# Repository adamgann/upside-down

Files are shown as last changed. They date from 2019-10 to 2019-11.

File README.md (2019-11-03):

# upside-down
Halloween 2019: The wall of lights from Stranger Things

---
In this costume an Arduino Uno, several shift registers (74HC595), and a handful of LEDs were used to create the wall from the first season of Stranger Things. The result can be seen [in this video](https://www.youtube.com/watch?v=mKRO_VgZO74) and the build process is discussed in [this blog post](http://adamgannon.com/2019/11/03/an-arduino-powered-stranger-things-costume/).

All design files are available to use (see terms in LICENSE). A warning this was hacked together fairly quickly, so don't expect a graceful board layout or bug-free software. Please cite this repository or my blog.

---
## Files

### arduino/
Contains Arudino sketches. Partly based on examples from [Janis Rove](https://github.com/janisrove/Arduino-74HC595-shift-registers) and the folks at [Adafruit](https://learn.adafruit.com/adafruit-arduino-lesson-4-eight-leds/brightness-control).

The sketch `check_leds.ino` cycles through each letter of the alphabet to verify wiring is correct.

The sketch `main.ino` runs through the light sequence.

### eagle/
Contains schematic and design files for the PCB. The project name is `shift_register_board`. Huge thanks to the [Sparkfun Eagle library](https://github.com/sparkfun/SparkFun-Eagle-Libraries) for footprints.

### graphics/
Files for the silkscreen logo added to the board. I followed the Eagle BMP import process discussed [in this tutorial](https://learn.sparkfun.com/tutorials/importing-custom-images-into-eagle/method-3-import-bmp).

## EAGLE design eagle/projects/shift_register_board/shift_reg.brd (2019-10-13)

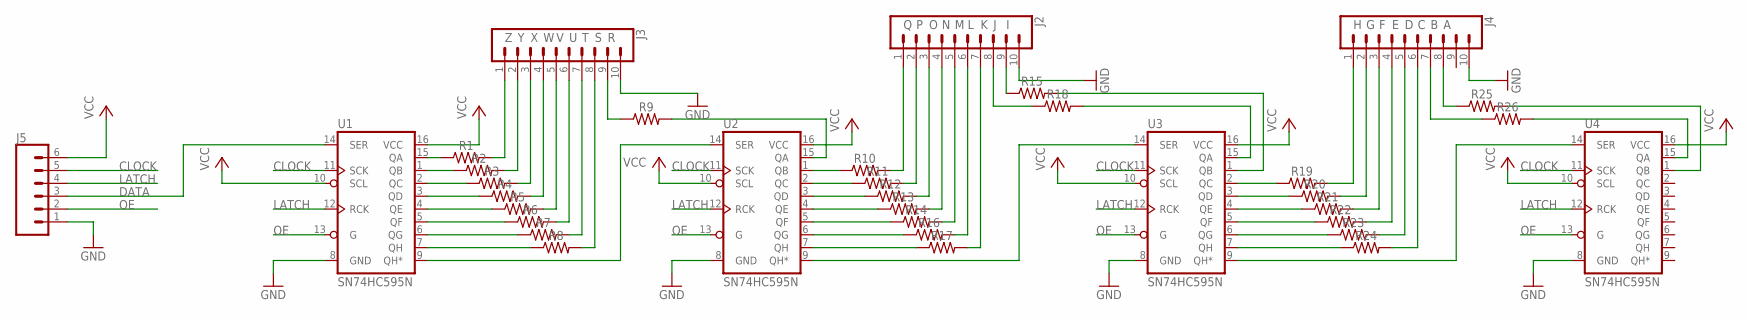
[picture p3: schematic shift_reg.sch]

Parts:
J2, J3, J4: CONN_10"; 1X10
J5: CONN_06LOCK; 1X06_LOCK
R1, R2, R3, R4, R5, R6, R7, R8, R9, R10, R11, R12, R13, R14, R15, R16, R17, R18, R19, R20, R21, R22, R23, R24, R25, R26: AXIAL-0.3
U1, U2, U3, U4: SN74HC595N; DIP16

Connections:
A: J4.8, R25.P$1 (1)
B: J4.7, R26.P$1 (1)
C: J4.6, R24.P$2 (2)
CLOCK: J5.5, U1.11 (SCK), U2.11 (SCK), U3.11 (SCK), U4.11 (SCK)
D: J4.5, R23.P$2 (2)
DATA: J5.3, U1.14 (SER)
E: J4.4, R22.P$2 (2)
F: J4.3, R21.P$2 (2)
G: J4.2, R20.P$2 (2)
GND: J2.10, J3.10, J4.10, J5.1, U1.8 (GND), U2.8 (GND), U3.8 (GND), U4.8 (GND)
H: J4.1, R19.P$2 (2)
I: J2.9, R15.P$1 (1)
J: J2.8, R18.P$1 (1)
K: J2.7, R17.P$2 (2)
L: J2.6, R16.P$2 (2)
LATCH: J5.4, U1.12 (RCK), U2.12 (RCK), U3.12 (RCK), U4.12 (RCK)
M: J2.5, R14.P$2 (2)
N: J2.4, R13.P$2 (2)
unnamed: U1.9 (QH*), U2.14 (SER)
unnamed: R9.P$2 (2), U2.15 (QA)
unnamed: R14.P$1 (1), U2.5 (QF)
unnamed: R18.P$2 (2), U3.15 (QA)
unnamed: R15.P$2 (2), U3.1 (QB)
unnamed: R1.P$1 (1), U1.15 (QA)
unnamed: R2.P$1 (1), U1.1 (QB)
unnamed: R3.P$1 (1), U1.2 (QC)
unnamed: R4.P$1 (1), U1.3 (QD)
unnamed: R5.P$1 (1), U1.4 (QE)
unnamed: R6.P$1 (1), U1.5 (QF)
unnamed: R7.P$1 (1), U1.6 (QG)
unnamed: R8.P$1 (1), U1.7 (QH)
unnamed: R10.P$1 (1), U2.1 (QB)
unnamed: R11.P$1 (1), U2.2 (QC)
unnamed: R12.P$1 (1), U2.3 (QD)
unnamed: R13.P$1 (1), U2.4 (QE)
unnamed: R16.P$1 (1), U2.6 (QG)
unnamed: R17.P$1 (1), U2.7 (QH)
unnamed: R19.P$1 (1), U3.2 (QC)
unnamed: R20.P$1 (1), U3.3 (QD)
unnamed: U2.9 (QH*), U3.14 (SER)
unnamed: R21.P$1 (1), U3.4 (QE)
unnamed: R22.P$1 (1), U3.5 (QF)
unnamed: R23.P$1 (1), U3.6 (QG)
unnamed: R24.P$1 (1), U3.7 (QH)
unnamed: R26.P$2 (2), U4.15 (QA)
unnamed: R25.P$2 (2), U4.1 (QB)
unnamed: U3.9 (QH*), U4.14 (SER)
O: J2.3, R12.P$2 (2)
OE: J5.2, U1.13 (G), U2.13 (G), U3.13 (G), U4.13 (G)
P: J2.2, R11.P$2 (2)
Q: J2.1, R10.P$2 (2)
R: J3.9, R9.P$1 (1)
S: J3.8, R8.P$2 (2)
T: J3.7, R7.P$2 (2)
U: J3.6, R6.P$2 (2)
V: J3.5, R5.P$2 (2)
VCC: J5.6, U1.10 (SCL), U1.16 (VCC), U2.10 (SCL), U2.16 (VCC), U3.10 (SCL), U3.16 (VCC), U4.10 (SCL), U4.16 (VCC)
W: J3.4, R4.P$2 (2)
X: J3.3, R3.P$2 (2)
Y: J3.2, R2.P$2 (2)
Z: J3.1, R1.P$2 (2)

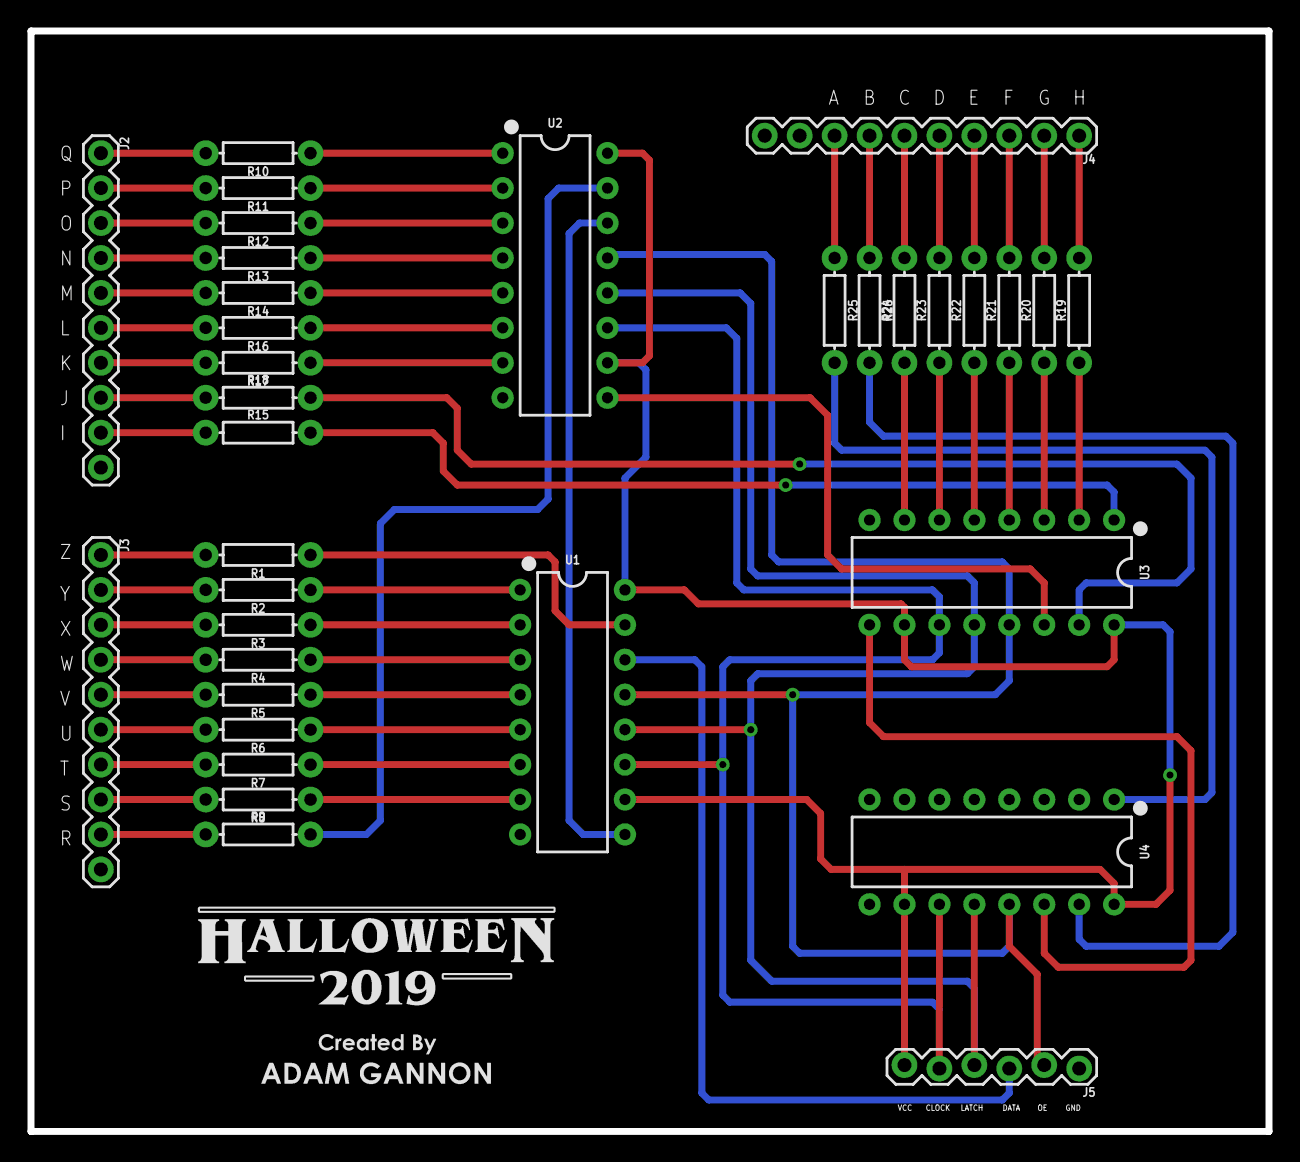
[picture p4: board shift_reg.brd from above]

Board: 2 copper layers, 90.0 x 80.0 mm, 34 parts (0 on the bottom side), 61 nets.

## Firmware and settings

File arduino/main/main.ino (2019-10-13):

/*

Play the main sequence on the wall. 

Adam Gannon - October 2019. 

 */
#include <avr/sleep.h>

// The first LED (A) is at register value 6
// The last LED (Z) is at register value 32
const int REG_START = 6;
const int REG_STOP = 32;


// The external button
const int buttonPin = 2;     // the number of the pushbutton pin
// The onboard LED for status
const int ledPin =  13;      // the number of the LED pin
//Pin connected to ST_CP of 74HC595
int latchPin = 5;
//Pin connected to SH_CP of 74HC595
int clockPin = 6;
////Pin connected to DS of 74HC595
int dataPin = 4;
// Pin connected to OE of 74HC595
int outputEnablePin = 3;

// Globals for LED registers 
int numOfRegisters = 4;
byte* registerState;


void setup() {

  // Seed our RNG by reading noise
  randomSeed(analogRead(0));
  
  //Initialize array
  registerState = new byte[numOfRegisters];
  for (size_t i = 0; i < numOfRegisters; i++) {
    registerState[i] = 0;
  }

  //set pins to output so you can control the shift register
  pinMode(latchPin, OUTPUT);
  pinMode(clockPin, OUTPUT);
  pinMode(dataPin, OUTPUT);
  pinMode(outputEnablePin, OUTPUT);

  // LEDs can be *really* bright, particularly at a dark party. Tone it down a little
  setBrightness(125);

  // initialize the onboard LED pin as an output:
  pinMode(ledPin, OUTPUT);
  // initialize the pushbutton pin as an input:
  pinMode(buttonPin, INPUT);

  // Start with nothing displayed on the LEDs
  clear_reg();
  write_all(LOW);
  
}

void loop() 
{

  // Wait on button press to start sequence.
  // Use the onboard LED for status
  wait_on_button();
  digitalWrite(ledPin,HIGH);
  run_once();
  digitalWrite(ledPin,LOW);
  
 

}

// Blocking call that waits until the state of the button changes 
void wait_on_button()
{
  EIFR = _BV (INTF0);
  sleep_enable();
  attachInterrupt(digitalPinToInterrupt(buttonPin),wake_up,CHANGE);
  set_sleep_mode(SLEEP_MODE_PWR_DOWN);
  sleep_cpu(); //Stays here until interrupt is fired
}
void wake_up()
{
  sleep_disable();
  detachInterrupt(digitalPinToInterrupt(buttonPin));
}


// Run the whole sequence once
void run_once()
{
  
  // "Okay. Okay baby talk to me"
  delay(5000);
  int right_delay[] = {5000,2000,1200,1500,1500};
  int here_delay[] = {2000,1000,1000,1000};
  flash_phrase("RIGHT",right_delay);
  flash_phrase("HERE",here_delay);

  // "Right here? I don't know what that means?
  // Lights are all off during this
  delay(13000);
  
  // "What should I do?"
  int run_delay[] = {2000,3000,3500};
  flash_phrase("RUN",run_delay);
  delay(200);

  // Oh shit!
  flash_all(15000);
}


// The demogorgon sequence. Flash a random chunk of LEDs for flash_time
// Randomize the time on and off between flashes. 
void flash_all(int flash_time)
{
  unsigned long start_time = millis();
  while( (millis() - start_time) < flash_time )
  {
    long rand_on_time = random(40,80);
    long rand_off_time = random(40,80);
    
    rand_on();
    delay(rand_on_time);
    write_all(LOW);
    clear_reg();
    delay(rand_off_time);
  }
  
}

void rand_on()
{
  // Number of simultaneous LEDs that are on
  long rand_leds = random(4,26); 

  for (int iled=0;iled<rand_leds;iled++)
  {
    long rand_letter = random(REG_START,REG_STOP+1); //Register values of A-Z
    regWrite(rand_letter,HIGH);    
  }

}


// Clear the register state vector
void clear_reg()
{
  for (int ii=0;ii<numOfRegisters;ii++)
  {
    registerState[ii] = 0;
  }
}


// Letters flash one after another, without pause.
// Each letter is up for about 2 seconds
void flash_phrase(String phrase, int delay_vec[])
{
  for (int ii=0;ii<phrase.length();ii++)
  {
    write_letter(phrase[ii],delay_vec[ii]);
  }  
}



// Flash a single letter for delay_val milliseconds
// This function accepts capital letters only (65-90)
void write_letter(char letter, int delay_val)
{
    // ALPHA_START (6) is the start of the register.
    // 65 is the ASCII value of 'A', the first letter
    int reg_val = letter - 65 + REG_START;

    // Turn on and hold
    regWrite(reg_val,HIGH);
    delay(delay_val);
    regWrite(reg_val,LOW);
}

void write_all(bool state)
{
  byte states;
  if (state == LOW)
  {
    states = 0;
  }
  else
  {
    states = 255;
  }
  
  digitalWrite(latchPin, LOW);
  for (int i = 0; i < numOfRegisters; i++)
  {
    shiftOut(dataPin, clockPin, LSBFIRST, states);
  }
  digitalWrite(latchPin, HIGH);
}


void regWrite(int pin, bool state){
  /* https://github.com/janisrove/Arduino-74HC595-shift-registers */
  //Determines register
  int reg = pin / 8;
  //Determines pin for actual register
  int actualPin = pin - (8 * reg);

  //Begin session
  digitalWrite(latchPin, LOW);

  for (int i = 0; i < numOfRegisters; i++){
    //Get actual states for register
    byte* states = &registerState[i];

    //Update state
    if (i == reg){
      bitWrite(*states, actualPin, state);
    }

    //Write
    shiftOut(dataPin, clockPin, LSBFIRST, *states);
  }

  //End session
  digitalWrite(latchPin, HIGH);
}

/* https://learn.adafruit.com/adafruit-arduino-lesson-4-eight-leds/brightness-control */
void setBrightness(byte brightness) // 0 to 255
{
  analogWrite(outputEnablePin, 255-brightness);
}

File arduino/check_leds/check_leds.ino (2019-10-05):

/*

 Runs through each letter of the alphabet, illuminating each in turn. 

 */

 
//Pin connected to ST_CP of 74HC595
int latchPin = 5;
//Pin connected to SH_CP of 74HC595
int clockPin = 6;
////Pin connected to DS of 74HC595
int dataPin = 4;

int outputEnablePin = 3;


int numOfRegisters = 4;
byte* registerState;

long effectId = 0;
long prevEffect = 0;
long effectRepeat = 0;
long effectSpeed = 30;

void setup() {
  //Initialize array
  registerState = new byte[numOfRegisters];
  for (size_t i = 0; i < numOfRegisters; i++) {
    registerState[i] = 0;
  }

  //set pins to output so you can control the shift register
  pinMode(latchPin, OUTPUT);
  pinMode(clockPin, OUTPUT);
  pinMode(dataPin, OUTPUT);

  setBrightness(25);
}

void loop() {
  for (int ii=6;ii<32;ii++)
  {
    regWrite(ii,HIGH);
    delay(500);
    regWrite(ii,LOW);
  }

  
}

void effectA(int speed){
  for (int i = 0; i < 16; i++){
    for (int k = i; k < 16; k++){
      regWrite(k, HIGH);
      delay(speed);
      regWrite(k, LOW);
    }

    //regWrite(i, HIGH);
  }
}

void effectB(int speed){
  for (int i = 15; i >= 0; i--){
    for (int k = 0; k < i; k++){
      regWrite(k, HIGH);
      delay(speed);
      regWrite(k, LOW);
    }

    regWrite(i, HIGH);
  }
}

void effectC(int speed){
  int prevI = 0;
  for (int i = 0; i < 16; i++){
    regWrite(prevI, LOW);
    regWrite(i, HIGH);
    prevI = i;

    delay(speed);
  }

  for (int i = 15; i >= 0; i--){
    regWrite(prevI, LOW);
    regWrite(i, HIGH);
    prevI = i;

    delay(speed);
  }
}

void effectD(int speed){
  for (int i = 0; i < 8; i++){
    for (int k = i; k < 8; k++)
    {
      regWrite(k, HIGH);
      regWrite(15 - k, HIGH);
      delay(speed);
      regWrite(k, LOW);
      regWrite(15 - k, LOW);
    }

    regWrite(i, HIGH);
    regWrite(15 - i, HIGH);
  }
}

void effectE(int speed){
  for (int i = 7; i >= 0; i--){
    for (int k = 0; k <= i; k++)
    {
      regWrite(k, HIGH);
      regWrite(15 - k, HIGH);
      delay(speed);
      regWrite(k, LOW);
      regWrite(15 - k, LOW);
    }

    regWrite(i, HIGH);
    regWrite(15 - i, HIGH);
  }
}

void regWrite(int pin, bool state){
  /* https://github.com/janisrove/Arduino-74HC595-shift-registers */
  //Determines register
  int reg = pin / 8;
  //Determines pin for actual register
  int actualPin = pin - (8 * reg);

  //Begin session
  digitalWrite(latchPin, LOW);

  for (int i = 0; i < numOfRegisters; i++){
    //Get actual states for register
    byte* states = &registerState[i];

    //Update state
    if (i == reg){
      bitWrite(*states, actualPin, state);
    }

    //Write
    shiftOut(dataPin, clockPin, LSBFIRST, *states);
  }

  //End session
  digitalWrite(latchPin, HIGH);
}

/* https://learn.adafruit.com/adafruit-arduino-lesson-4-eight-leds/brightness-control */
void setBrightness(byte brightness) // 0 to 255
{
  analogWrite(outputEnablePin, 255-brightness);
}

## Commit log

2019-10-05 Stepping through each LED in a 3-register chain
2019-10-05 Added script to check LEDs by flashing each one in turn
2019-10-05 First draft of schematic for shift register board
    [shift_reg.sch]
2019-10-08 Started board layout
    [shift_reg.brd, shift_reg.sch]
2019-10-10 Routed board.
    [shift_reg.brd]
2019-10-12 Board layout using SMD components
    [shift_reg.brd]
2019-10-12 Laid out board with through holes. Ready for pour
    [shift_reg.brd, shift_reg.sch]
2019-10-13 Looks like PCB Way will work. Ready to finalize design for manufacture
    [shift_reg.brd]
2019-10-13 Added pours and silkscreen text. Ready for images
    [shift_reg.brd]
2019-10-13 Files as submitted to PCBway
    [shift_reg.brd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]
2019-10-13 Wired in button to start the sequence when pressed
2019-10-13 Using an interrupt to sleep between button presses.
2019-10-26 Fixed board outline per PCB Way. Submitted updated Gerber files and design passed
    [copper_bottom.gbr, copper_top.gbr, drills.xln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]

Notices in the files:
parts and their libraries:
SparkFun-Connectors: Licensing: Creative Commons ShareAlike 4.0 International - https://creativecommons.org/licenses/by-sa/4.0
